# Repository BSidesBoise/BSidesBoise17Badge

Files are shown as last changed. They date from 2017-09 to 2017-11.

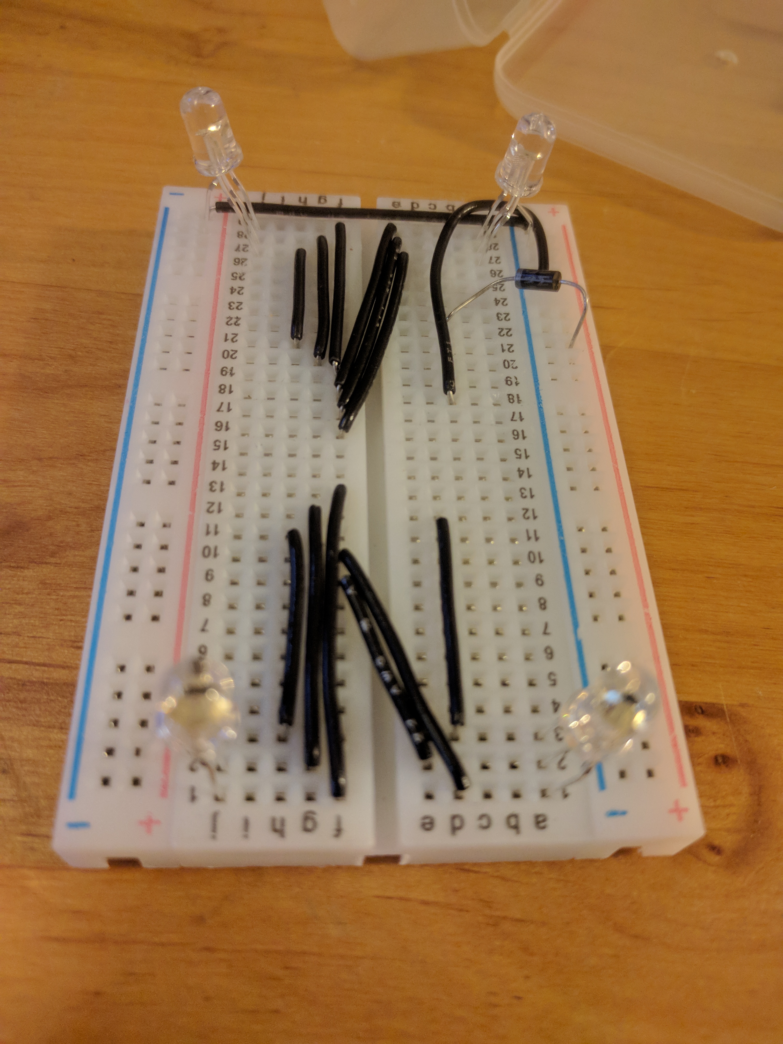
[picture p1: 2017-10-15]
docs/Wiring_Reference_3.jpg

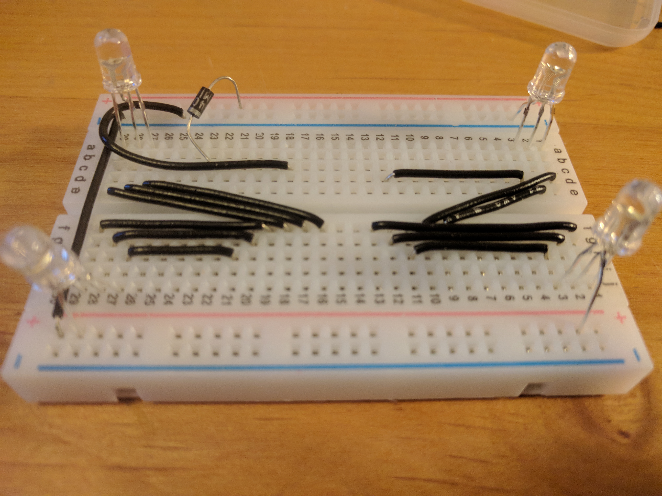
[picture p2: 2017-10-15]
docs/Wiring_Reference_2.jpg

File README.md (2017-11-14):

# BSides Boise 2017 Electronic Badge

The concept we had for this years badge was a 'hackable' badge that attendees
could hack on while at the con. We wanted it to be accessible and useful post-con as well.

We chose the Lolin ESP-12 NodeMCU clone using an ESP8266 chipset as the MCU, and
decided to mount it on a 30 pin breadboard with 4 RGB LED's. This would give us the
requisite bling, and give attendees some easy visual feedback for learning how to
control the MCU.

We also chose to use the Arduino IDE for ease of access by attendees.
[here](http://www.instructables.com/id/Programming-ESP8266-ESP-12E-NodeMCU-Using-Arduino-/) is a very useful writeup on how to configure the IDE for the Lolin.
You can also find the steps under docs/building.md

Also included under the docs folder are the datasheets for the LED's and the Lolin NodeMCU clone.

@badgerops also created a Fritzing project for this badge located at docs/fritzing project

We hope you enjoy hacking on this badge, and can't wait to see what people make it do!

- The BSides Boise 2017 Badge team

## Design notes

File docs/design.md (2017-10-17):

BSides Boise 2017 Badge Design
==============================
This years badge is purposely stupid simple for a couple of reasons:
* We procrastinated, and therefore time constrained
* We were budget constrained due to sponsor issues (Note for sponsors, _please_
  get your funding in fast so we have time to plan cooler badges in the future)
  
The goal of this years badge was to be a development kit that would allow (and 
encourage) attendees to hack it. This is why it's presented on a development 
board.

The Micro-Controller
-------------------
We chose the NodeMCU micro-controller because it's a chip we haven't worked with
before and we wanted to play with it, but it also gives an impressive amount of
capability at a very low cost. The hope is that this simple platform may allow a
foundation from which we can build on for future badges. (Unless we find a
cooler toy)

The Firmware
------------
The firmware was written using the Arduino platform, again, to try to make the
badge as friendly to new hackers as possible. To learn how to program the
firmware yourself, please see [The Building Instructions](building.md)

The design of the firmware consists of two objects and a Moment struct.

### Moment
The Moment is defined in the patterns.h file, and defines a moment in time for
all system LED's including information about how long the system should remain
in that moment, and how it transitions into it.

See the patterns.h header file for more information.

### Led_pin
This object wraps a single LED pin (which there are three of for each tri-color
LED) and handles how that pin gets manipulated. This is the only object that
needs to have knowledge over the fact that the PWM goes between 1 and 1024. As
far as all other objects are concerned, they're setting a percentage brightness
between 0 and 100.

See class documentation for more information.

### Leds
This object, upon creation, populates an array of Led_pin objects and 
initializes them to their initial values and associates them with their initial
values. This object controls all LEDs from a top-level and provides the public
API to other objects in the system.

The fade_to method of this object does the majority of the work in setting all
system LEDs to a specified state. Using information provided within the Moment
struct, it executes the transition into the specified Moment. 

The draw method sits at a higher level uses the fade_to method transition to an
array of Moments provided to the draw method in turn, providing a smooth flow
between Moments. 

### loop
The loop function is where we draw the various LED patterns we're using for the
badge. This is also where potential future functionality will live. Feel free
and extend or modify this firmware as you see fit!

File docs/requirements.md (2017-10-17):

Boise BSides 2017 Badge Functionality
=====================================
This document outlines the expected functionality for the BSides badge.

Microcontroller
---------------
https://nodemcu.readthedocs.io/en/master/
http://www.esp8266.com/wiki/doku.php?id=nodemcu-unofficial-faq

LEDs
----
The LED's require less voltage than our output pins deliver. In order to 
reduce voltage, we'll use PWM.

Patterns
--------
TODO - We need to figure out what patterns to draw for which badges.

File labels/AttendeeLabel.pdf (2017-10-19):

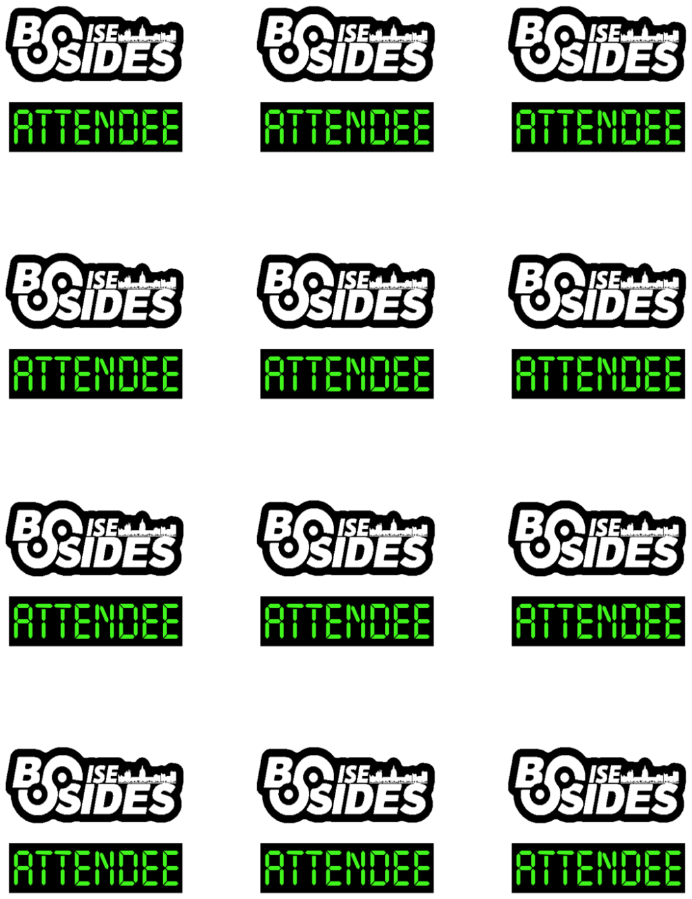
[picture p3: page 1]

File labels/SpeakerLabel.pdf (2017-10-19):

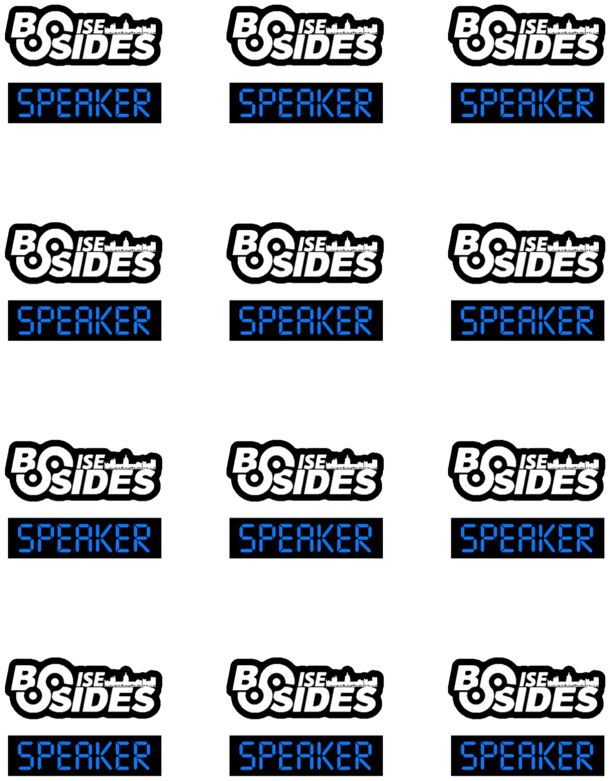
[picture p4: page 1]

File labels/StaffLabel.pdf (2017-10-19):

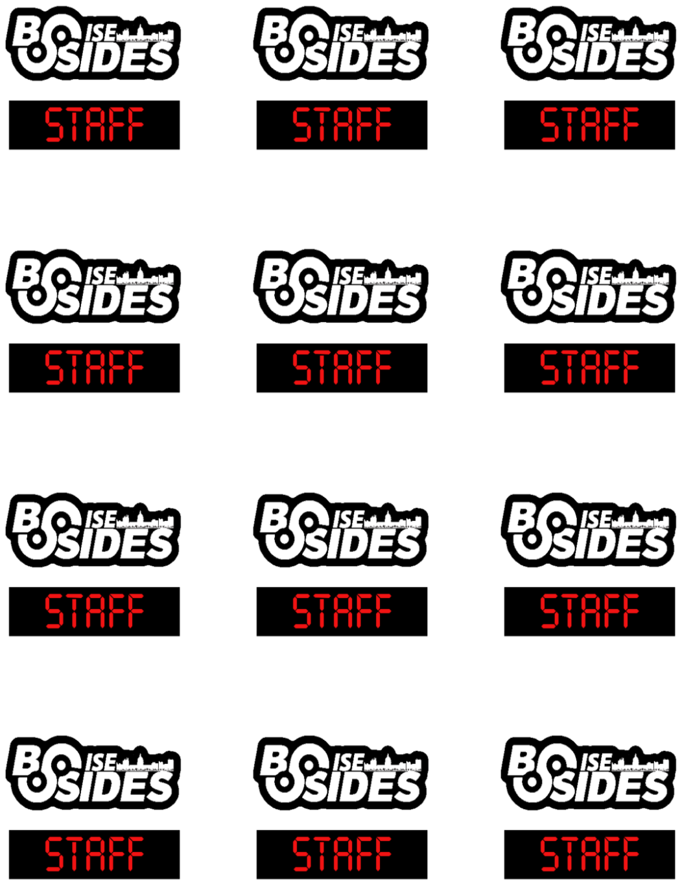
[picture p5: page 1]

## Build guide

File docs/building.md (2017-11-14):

Building the Badge
==================

Building the hardware & pin outs
--------------------------------
The NodeMCU can be powered off USB or by battery via the Vin 5v input pin. 
__It's crucial__ that only one power source is connected at a time to prevent 
hardware damage.Below is a simple diagram of the NodeMCU module and its pins 
which are described in more detail in the tables following.

### Key:
* N/C  = Not Connected
* GND  = Ground
* 5v   = 5 Volt power input from battery
* 3.3v = 3.3 Volt power output to peripheral power rails.
* LED  = Output pins connected to the an LED (See LED section below)

<pre>
        ------------
N/C  <- | A0    D0 | -> LED
GND  <- | G     D1 | -> LED
N/C  <- | VU    D2 | -> LED
LED  <- | S3    D3 | -> LED
N/C  <- | S2    D4 | -> LED
N/C  <- | S1    3V | -> 3.3v
N/C  <- | SC     G | -> GND
N/C  <- | S0    D5 | -> LED
N/C  <- | SK    D6 | -> LED
GND  <- | G     D7 | -> LED
3.3v <- | 3V    D8 | -> LED
N/C  <- | EN    RX | -> LED
N/C  <- | RST   TX | -> LED
GND  <- | G      G | -> GND
5v   <- | VIN   3V | -> 3.3v
        ------------
</pre>

### Wiring
For laying wiring the boards, please refer to the wiring diagram images:

https://github.com/BSidesBoise/BSidesBoise17Badge/blob/master/docs/Wiring_Reference_1.jpg

https://github.com/BSidesBoise/BSidesBoise17Badge/blob/master/docs/Wiring_Reference_2.jpg

https://github.com/BSidesBoise/BSidesBoise17Badge/blob/master/docs/Wiring_Reference_3.jpg

__PLEASE READ AND FOLLOW THE FOLLOWING INSTRUCTIONS CAREFULLY__:

1) The board is orientated so that the row numbers go from 1 at the top to 30 at 
   the bottom.

1) The "top" of the NodeMCU is the side with the ESP8266 chip.

1) The NodeMCU shall be placed with the first pin at the top of the board, on 
   the #9 row of the protoboard.

1) You _MUST_ ensure that all wires leave the "a", "b", "i", and "j" columns of 
   the protoboard empty so as to accommodate all NodeMCU's hardware platforms.

1) You _MUST_ ensure that the red LED pin is always the bottom-most (as 
   referenced to the protoboard) pin of the three colors.  This means two of 
   the LEDs on the right, will be in mirror orientation to the two on the left 
   to keep the red LED pointed down.

1) You should clip your LED pins so that the LED will bump up against, or nearly 
   bump up against the top of the project box, when inserted. This will ensure 
   that the LEDs don't work their way out (they will naturally want walk out of 
   the board due to the springy nature of their pins).

1) Please make sure you get the orientation of your diode correct (see above 
   picture)

1) Please hook up the common cathode rail of the LEDs as per the image so that 
   they are all commoned to one GND line on the left side of the board.

1) Please check out the master branch of the repository, then follow the 
   instructions below and compile it for your device (making sure to 
   comment/uncomment the S3 line that is correct for if you have a legit 
   NodeMCU or a Lolin clone), then test each finished board to make sure it 
   lights up correctly.

1) For the most part, the LEDs should be placed at the far extent of the board. 
   The bottom two should be one row up, to make room for the common line 
   connecting the rails on both sides of the board.

Here is the table of wiring directions which will help you, in conjunction with 
the above image:

LED Position | NodeMCU Pin | Protoboard Row | LED Color 
-------------|-------------|----------------|----------
TL           | S3 (SD3)    | 12             | R
TL           | D0          | 9              | G
TL           | D1          | 10             | B
TR           | D2          | 11             | R
TR           | D3          | 12             | G
TR           | D4          | 13             | B
BL           | D5          | 16             | R
BL           | D6          | 17             | G
BL           | D7          | 18             | B
BR           | D8          | 19             | R
BR           | RX          | 20             | G
BR           | TX          | 21             | B

Building the firmware
---------------------
The POC is built using the Arduino IDE using the ESP8266 board libraries.
Docs are located [here.](https://arduino-esp8266.readthedocs.io/en/latest/)

1. Start the Arduino IDE (1.8.4 was used at the time of this writing)
1. Configure the sketchbook for the poc folder. 
    * Select File -> Preferences -> settings tab and change the "Sketchbook 
    location" to this poc folder.
1. Add the ESP8266 board
    * Select File -> Preferences -> settings tab and in the "Additional Boards
    Manager URLs" add 
    `http://arduino.esp8266.com/stable/package_esp8266com_index.json`
1. Install the board package
    * Select Tools -> Board -> Boards Manager and search for "NodeMCU" and select Install
1. Choose comms port
    * Select Tools -> Port -> Choose the COM port corresponding to your USB cable.
1. Oepn an .ino file
    * Select File -> Open -> Choose an .ino file within this repo.
1. Upload the firmware
    * Open the [firmware](../firmware/LEDs/LEDs.ino) file using the Arduino IDE
    * Select the "Upload" button to compile and upload the firmware to the 
      NodeMCU

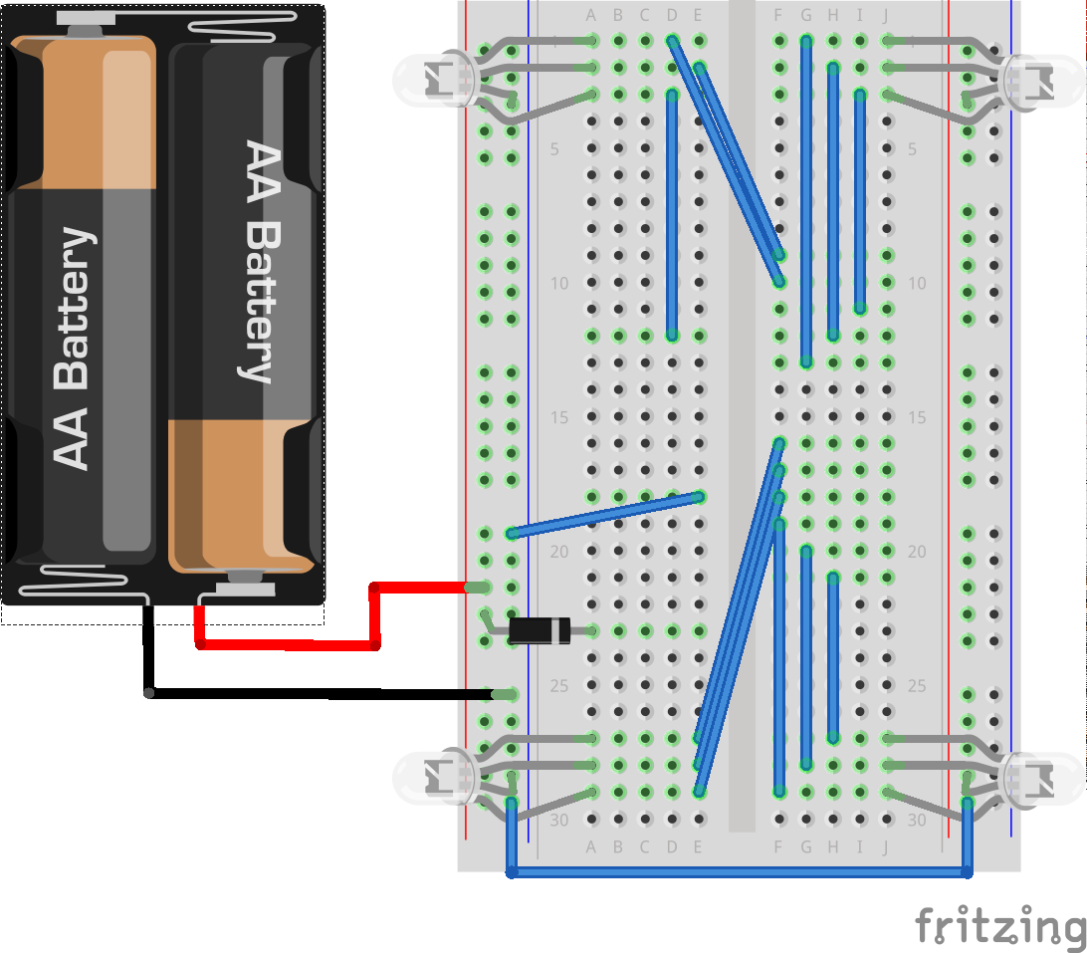
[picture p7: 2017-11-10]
docs/Wiring Diagram.png

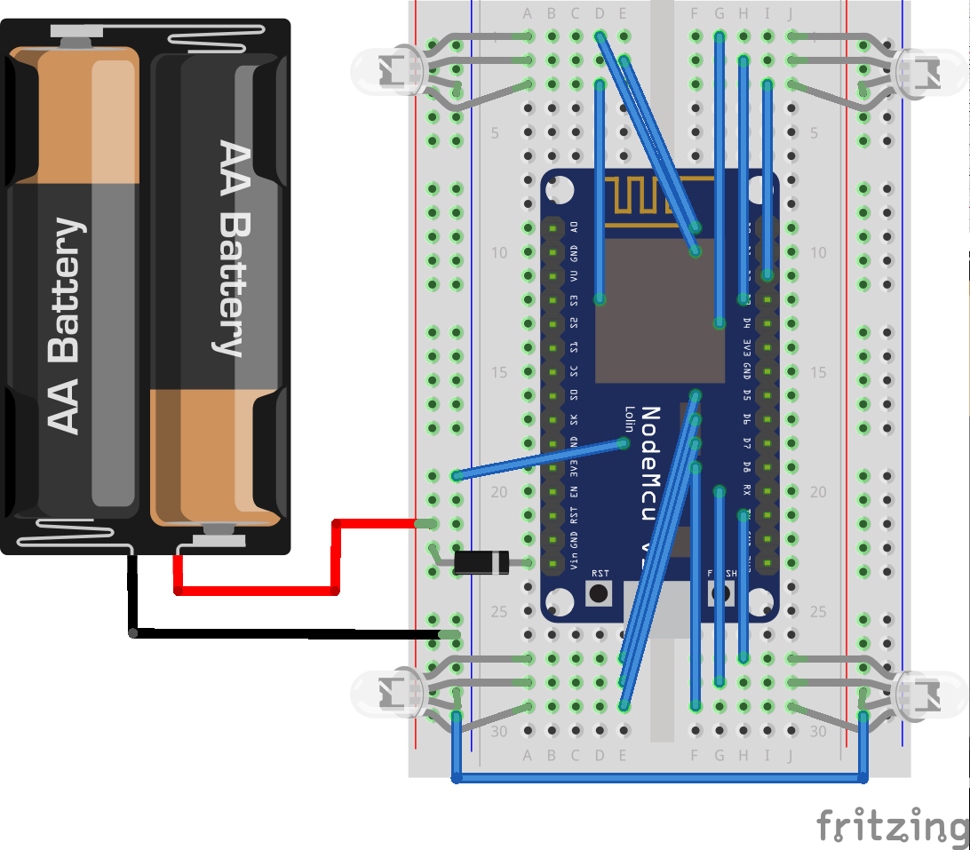
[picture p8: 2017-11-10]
docs/Wiring diagram with MCU.png

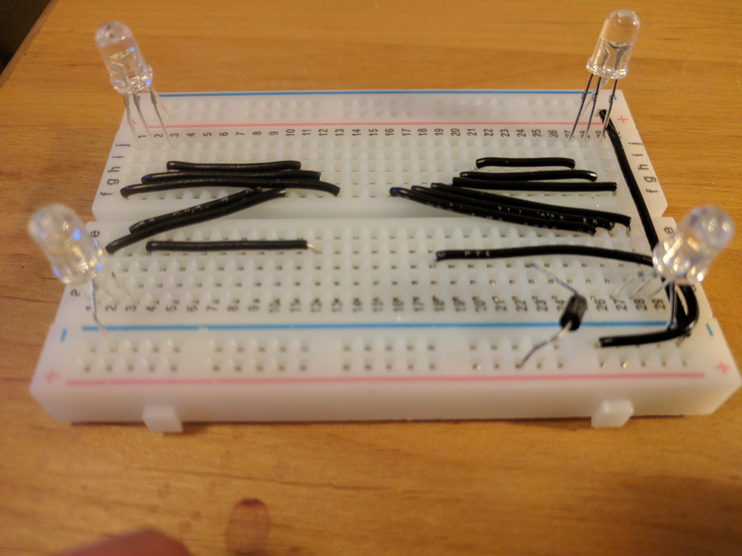
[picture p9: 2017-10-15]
docs/Wiring_Reference_1.jpg

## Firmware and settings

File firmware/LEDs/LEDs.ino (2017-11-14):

/*******************************************************************************
 * This sketch defines the 2017 BSidesBoise badge.
 * 
 * See design.md for more information on how this firmware works.
 ******************************************************************************/
#include "patterns.h"

/*******************************************************************************
 * Constants used throughout this sketch
 ******************************************************************************/
// Constants defining PWM min/max values
//#define MAXRED 350
//#define MAXLED 50
//#define MINLED 1023

//#define MAXRED 674
//#define MAXLED 974
//#define MINLED 0

#define MAXRED 174
#define MAXLED 287
#define MINLED 0

// GPIO pin that's not defined elsewhere by Arduino:
//#define S3 9 //For LOLIN clone due to bug
#define S3 10 //For legitimate NodeMCU
#define RX 3
#define TX 1

/*******************************************************************************
 * Object that abstracts a single LED Pin (a third of a tri-color LED) and
 * controls allowed value setting.
 ******************************************************************************/
class Led_pin
{
public:
    /***************************************************************************
     * Constructor
     * @param[in] led The GPIO pin defining this LED
     * @param[in] initial_brightness The initial brightness of this LED
     * @param[in] max_brightness The maximum brightness PWM level for this LED
     * @param[in] min_brightness The minimum brightness PWM level for this LED
     *
     * Initializes LED pin as outputs and sets it to initial brightness.
     **************************************************************************/
    Led_pin(int led, uint16_t initial_brightness, uint16_t max_brightness,
            uint16_t min_brightness) : m_led(led),
                                       m_brightness(initial_brightness),
                                       m_max_brightness(max_brightness),
                                       m_min_brightness(min_brightness)
    {
        // Set the initial value.
        pinMode(m_led, OUTPUT);
        analogWrite(m_led, m_brightness);
    }

    /***************************************************************************
     * Set the PWM value for this LED
     *
     * @param[in] percent_value The PWM value to set in percentage from 0-100
     *
     * @return The current brightness of this LED in percentage between 0-100
     *
     * @remarks Clamps pwm value to min or max value for this LED.
     **************************************************************************/
    uint8_t set_pwm(uint8_t percent_value)
    {
        // Convert percent to real PWM values in the range of this LED
        uint16_t pwm_value = map(percent_value, 0, 100, m_min_brightness,
                                 m_max_brightness);

        if (pwm_value < m_min_brightness)
        {
            // The user tried to set the brightness above the minimum, clamp it
            m_brightness = m_min_brightness;
        }
        else if (pwm_value > m_max_brightness)
        {
            // The user tried to set the brightness below the maximum, clamp it
            m_brightness = m_max_brightness;
        }
        else
        {
            // Set whatever the user specified.
            m_brightness = pwm_value;
        }

        // Now set the value
        analogWrite(m_led, m_brightness);
        return percent_value;
    }

private:
    // This LED pin.
    int m_led;

    // The current brightness value in PWM value between 0-1024.
    uint16_t m_brightness;

    // The min/max values that this LED will tolerate.
    uint16_t const m_max_brightness;
    uint16_t const m_min_brightness;
};

/*******************************************************************************
 * Top-level object controls the whole system's LED's and draws patterns with
 * them.
 ******************************************************************************/
class Leds
{
public:
    /***************************************************************************
     * Constructor
     *
     * @remarks Turns all LED's off initially
     **************************************************************************/
    Leds() : m_pin_array(
            {
                    // Top Left Red
                    Led_pin(S3, MINLED, MAXRED, MINLED),
                    // Top Left Green
                    Led_pin(D0, MINLED, MAXLED, MINLED),
                    // Top Left Blue
                    Led_pin(D1, MINLED, MAXLED, MINLED),
                    // Top Right Red
                    Led_pin(D2, MINLED, MAXRED, MINLED),
                    // Top Right Green
                    Led_pin(D3, MINLED, MAXLED, MINLED),
                    // Top Right Blue
                    Led_pin(D4, MINLED, MAXLED, MINLED),
                    // Bottom Left Red
                    Led_pin(D7, MINLED, MAXRED, MINLED),
                    // Bottom Left Green
                    Led_pin(D6, MINLED, MAXLED, MINLED),
                    // Bottom Left Blue
                    Led_pin(D5, MINLED, MAXLED, MINLED),
                    // Bottom Right Red
                    Led_pin(D8, MINLED, MAXRED, MINLED),
                    // Bottom Right Green
                    Led_pin(RX, MINLED, MAXLED, MINLED),
                    // Bottom Right Blue
                    Led_pin(TX, MINLED, MAXLED, MINLED)
            }),
             m_brightness{0, 0, 0, 0, 0, 0, 0, 0, 0, 0, 0, 0}
    {
        // Nothing to do here.
    }

    /***************************************************************************
     * Sets all LEDs from their current brightness to their specified brightness
     * handling fade times.
     *
     * @param[in] state The Moment containing information about the state to
     *            transition into.
     **************************************************************************/
    void fade_to(Moment state)
    {
        // Loop until all LED's have faded to their set values
        while(true)
        {
            // Reset the done LED counter
            uint8_t done_leds = 0;

            // For every LED, check the current brightness against the state
            // brightness and determine if they need to change.
            for (int i = 0; i < NUMBER_OF_LEDS; i++)
            {
                if (m_brightness[i] != state.leds[i])
                {
                    // Fade the LED a bit in the right direction
                    if (state.leds[i] < m_brightness[i])
                    {
                        if (state.fade_speed > 0)
                        {
                            // Need to dim a bit
                            m_brightness[i] = m_pin_array[i].set_pwm(
                                    --m_brightness[i]);
                        }
                        else
                        {
                            // Set LED immediately
                            m_brightness[i] = m_pin_array[i].set_pwm(
                                    state.leds[i]);
                        }
                    }
                    else
                    {
                        if (state.fade_speed > 0)
                        {
                            // Need to brighten a bit (smaller PWM)
                            m_brightness[i] = m_pin_array[i].set_pwm(
                                    ++m_brightness[i]);
                        }
                        else
                        {
                            // Set LED immediately
                            m_brightness[i] = m_pin_array[i].set_pwm(
                                    state.leds[i]);
                        }
                    }
                }
                else
                {
                    // We don't need to touch this LED, it's already set.
                    done_leds++;
                }
            }
            delay(state.fade_speed);

            // Check to see if we're done fading all LED's yet
            if (done_leds == NUMBER_OF_LEDS)
            {
                return;
            }
        }
    }

    /***************************************************************************
     * Draws an LED pattern using an array of Moments that define that pattern
     *
     * @param[in] pattern The moment array to draw
     * @param[in] pattern_size How many moments are in the array.
     **************************************************************************/
    void draw(Moment *pattern, uint8_t pattern_size)
    {
        for (int i = 0; i < pattern_size; i++)
        {
            fade_to(pattern[i]);
            delay(pattern[i].delay_time);
        }
    }

private:
    // An array of LED Pin's
    Led_pin m_pin_array[NUMBER_OF_LEDS];

    // An array of current LED brightness levels between 0-100%
    uint8_t m_brightness[NUMBER_OF_LEDS];
};

// Our system's LED's
Leds ZE_LEDS;

void setup()
{
    // Everything's done by the object initializer's.
}

// Generate random int to determine how many times to loop each Moment
int get_random(int min, int max)
{
    return random(min,max);
}

void loop_Unlock_patterns(){
    // Red/Blue 'cop' pattern #1
    for(int i = 0; i < get_random(4,10); i++){
        ZE_LEDS.draw(cop_pattern_1, sizeof(cop_pattern_1)/ sizeof(*cop_pattern_1)); 
    }
    // Red/Blue 'cop' pattern #2
    for(int i = 0; i < get_random(4,10); i++){
        ZE_LEDS.draw(cop_pattern_2, sizeof(cop_pattern_2)/ sizeof(*cop_pattern_2));
    };
}
void loop_Patterns(){
    // random loop Moment chase_rgb
    for(int i = 0; i < get_random(4,10); i++){
        ZE_LEDS.draw(chase_rgb, sizeof(chase_rgb)/ sizeof(*chase_rgb));
    }

    // Moment roy_g_biv
        ZE_LEDS.draw(roy_g_biv, sizeof(roy_g_biv)/ sizeof(*roy_g_biv));

    // random loop Moment chase_red
    for(int i = 0; i < get_random(0,8); i++){
        ZE_LEDS.draw(chase_red, sizeof(chase_red)/ sizeof(*chase_red));
    }    

    // random loop Moment chase_green
    for(int i = 0; i < get_random(0,8); i++){
        ZE_LEDS.draw(chase_green, sizeof(chase_green)/ sizeof(*chase_green));
    }    

    // random loop Moment chase_blue
    for(int i = 0; i < get_random(0,8); i++){
        ZE_LEDS.draw(chase_blue, sizeof(chase_blue)/ sizeof(*chase_blue));
    }

    // random loop Moment chase_white
    for(int i = 0; i < get_random(0,8); i++){
        ZE_LEDS.draw(chase_white, sizeof(chase_white)/ sizeof(*chase_white));
    }
    
    // random loop Moment pulse_bang
    for(int i = 0; i < get_random(1,6); i++){
        ZE_LEDS.draw(pulse_bang, sizeof(pulse_bang)/ sizeof(*pulse_bang));
    };
}
void loop()
{
    //ZE_LEDS.draw(test_pattern, sizeof(test_pattern)/ sizeof(*test_pattern));
    
    // criss_cross pattern on power on 
    // Followed by Member Mode
    // Followed by loop custom patterns  
    for(int i = 0; i < 1; i++){
        ZE_LEDS.draw(criss_cross, sizeof(criss_cross)/ sizeof(*criss_cross));
    }
    ZE_LEDS.draw(turn_off, sizeof(turn_off)/ sizeof(*turn_off));
    delay(1000);    

    // attendee_glow - GREEN
    // speaker_glow BLUE
    // staff_glow RED
    for(int i = 0; i < 10; i++){
        ZE_LEDS.draw(attendee_glow, sizeof(attendee_glow)/ sizeof(*attendee_glow));
    };   

    loop_Patterns();
    // Uncomment the following line for super sekret 'cop' pattern unlock
    //loop_Unlock_patterns();
    delay(1000);
}

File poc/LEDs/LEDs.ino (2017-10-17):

/*******************************************************************************
 * This sketch defines the 2017 BSidesBoise badge.
 * 
 * See design documents for more information on how this firmware works.
 ******************************************************************************/

/*******************************************************************************
 * Constants used throughout this sketch
 ******************************************************************************/
// Constants defining PWM min/max values
#define MAXRED 350
#define MAXLED 50
#define MINLED 1023

// GPIO pin that's not defined elsewhere by Arduino:
#define S3 9 //For LOLIN clone due to bug
//#define S3 10 //For legitimate NodeMCU
#define RX 3
#define TX 1

/*******************************************************************************
 * Object that abstracts a single LED Pin
 ******************************************************************************/
class Led_pin
{
public:
    /***************************************************************************
     * Constructor
     * @param[in] led The GPIO pin defining this LED
     * @param[in] initial_brightness The intial brightness of this LED
     * @param[in] max_brightness The maximum brightness PWM level for this LED
     * @param[in] min_brightness The minimum brightness PWM level for this LED
     *
     * Initializes LED pin as outputs and sets it to initial brightness.
     **************************************************************************/
    Led_pin(int led, uint16_t initial_brightness, uint16_t max_brightness,
            uint16_t min_brightness) : m_led(led),
                                       m_brightness(initial_brightness),
                                       m_max_brightness(max_brightness),
                                       m_min_brightness(min_brightness)
    {
        pinMode(m_led, OUTPUT);
        analogWrite(m_led, m_brightness);
    }

    /***************************************************************************
     * Fade this LED from current brightness to off at the given rate.
     *
     * @param[in] fade_speed The speed in milliseconds to fade. Typically
     *            between 0 - 30.
     *
     * @remarks Uses this LED's current brightness setting as a starting point.
     **************************************************************************/
    void fade_off(uint8_t fade_speed)
    {
        // The PWM range is 0-1024. This is the step size to fade down per
        // fade_speed milliseconds.
        uint8_t fadeAmount = 10;

        while(true)
        {
            if (m_brightness >= (m_min_brightness - fadeAmount))
            {
                // Turn the LED full off and bail, we're done.
                m_brightness = m_min_brightness;
                analogWrite(m_led, m_brightness);
                break;
            }
            else
            {
                // Still fading
                delay(fade_speed);
            }

            // Fade a bit more
            m_brightness = m_brightness + fadeAmount;
            analogWrite(m_led, m_brightness);
        }
    }

    /***************************************************************************
     * Fade this LED from current brightness to on at the given rate.
     *
     * @param[in] fade_speed The speed in milliseconds to fade. Typically
     *            between 0 - 30.
     *
     * @remarks Uses this LED's current brightness setting as a starting point.
     **************************************************************************/
    void fade_on(uint8_t fade_speed)
    {
        // The PWM range is 0-1024. This is the step size to fade down per
        // fade_speed milliseconds.
        uint8_t fadeAmount = 10;

        while(true)
        {
            if (m_brightness <= fadeAmount)
            {
                // Turn the LED full on and bail, we're done.
                m_brightness = m_max_brightness;
                analogWrite(m_led, m_brightness);
                break;
            }
            else
            {
                // Still fading
                delay(fade_speed);
            }

            // Fade a bit more
            m_brightness = m_brightness - fadeAmount;
            analogWrite(m_led, m_brightness);
        }
    }

private:
    int m_led;
    uint16_t m_brightness;
    uint16_t m_max_brightness;
    uint16_t m_min_brightness;
};

/*******************************************************************************
 * Object that abstracts a tri-color LED
 ******************************************************************************/
class Led
{
public:
    /***************************************************************************
     * Constructor
     * @param[in] red The GPIO pin defining RED for this LED
     * @param[in] green The GPIO pin defining GREEN for this LED
     * @param[in] blue The GPIO pin defining BLUE for this LED
     *
     * Initializes LED pins as outputs and sets them high to turn LED's off.
     **************************************************************************/
    Led(Led_pin red, Led_pin green, Led_pin blue) : m_red_led(red),
                                                    m_green_led(green),
                                                    m_blue_led(blue)
    {
        // Nothing to see here, initialization happens at the LED pin level
    }

    /***************************************************************************
     * Pattern drawer
     *
     * @param[in] pattern
     *
     **************************************************************************/
    bool draw()
    {
        // TODO - For now, we'll just fade the three pins for testing
        m_red_led.fade_on(5);
        m_red_led.fade_off(5);
        m_green_led.fade_on(5);
        m_green_led.fade_off(5);
        m_blue_led.fade_on(5);
        m_blue_led.fade_off(5);
    }
    
private:
    // LED Pin's
    Led_pin m_red_led;
    Led_pin m_green_led;
    Led_pin m_blue_led;
};

/*******************************************************************************
 * Global Variables
 ******************************************************************************/
// Our system's LED's
Led_pin TLRED(S3, MINLED, MAXRED, MINLED);
Led_pin TLGREEN(D0, MINLED, MAXLED, MINLED);
Led_pin TLBLUE(D1, MINLED, MAXLED, MINLED);

Led_pin TRRED(D2, MINLED, MAXRED, MINLED);
Led_pin TRGREEN(D3, MINLED, MAXLED, MINLED);
Led_pin TRBLUE(D4, MINLED, MAXLED, MINLED);

Led_pin BLRED(D5, MINLED, MAXRED, MINLED);
Led_pin BLGREEN(D6, MINLED, MAXLED, MINLED);
Led_pin BLBLUE(D7, MINLED, MAXLED, MINLED);

Led_pin BRRED(D8, MINLED, MAXRED, MINLED);
Led_pin BRGREEN(RX, MINLED, MAXLED, MINLED);
Led_pin BRBLUE(TX, MINLED, MAXLED, MINLED);

Led TOP_LEFT(TLRED, TLGREEN, TLBLUE);
Led TOP_RIGHT(TRRED, TRGREEN, TRBLUE);
Led BOTTOM_LEFT(BLRED, BLGREEN, BLBLUE);
Led BOTTOM_RIGHT(BRRED, BRGREEN, BRBLUE);
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

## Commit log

2017-09-09 Fixed BGR LED's in the pinout
2017-10-09 Initial proof-of-concept for the four LED's for the badge
2017-10-15 Functioning LED driver with a sample pattern
2017-10-15 Updated firmware to work with inverted LED's and fixed min/max values
    [LEDs.ino]
2017-10-15 Reference wiring screenshot.
2017-10-15 Better image of wiring diagram
2017-10-15 Update building.md with wiring information, and removed old information.
2017-10-15 Better wiring pictures
2017-10-17 Fix Max RED values for two of the three LEDs
    [LEDs.ino]
2017-10-19 Fixed a pinout bug in the firmware for the lower left LED
    [LEDs.ino]
2017-10-25 Attendee, Staff, and Speaker no longer fade out to off
    [LEDs.ino]
2017-10-26 Changed LED fade time - faster 15 in Patterns.h
    added loop ideas and commented them out in LEDs.ino
2017-11-02 fixed blue glow speaker pattern
    [LEDs.ino]
2017-11-10 added fritzing diagrams and documentation
    [BsidesBoise2017.fzz]
2017-11-10 Updated docs to fix a couple errors
    [LEDs.ino]
